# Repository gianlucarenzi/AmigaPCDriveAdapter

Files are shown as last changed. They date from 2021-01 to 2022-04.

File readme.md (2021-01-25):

# Amiga Floppy to PC Floppy Adapter

Created by Gianluca Renzi (C) 2018
 E-Mail:
- <icjtqr@gmail.com>
- <gianlucarenzi@eurek.it>

# PCB Revision History

- V0.1 Initial Revision 2018 Made with Kicad 4.x
- V1.0 First (BAD) PCB revision from transition from Kicad 4.x to Kicad 5.x
- V2.0 PCB Revision entirely made on Kicad 5. No library from Kicad 4 anymore.

# What is it?
It is a simple but powerful adapter to use internally in any Amiga Computer!
It must be connected to the floppy disk drive 34-pin interface on the drive
itself, then hooked up with the original cables from Amiga motherboard.

# Images
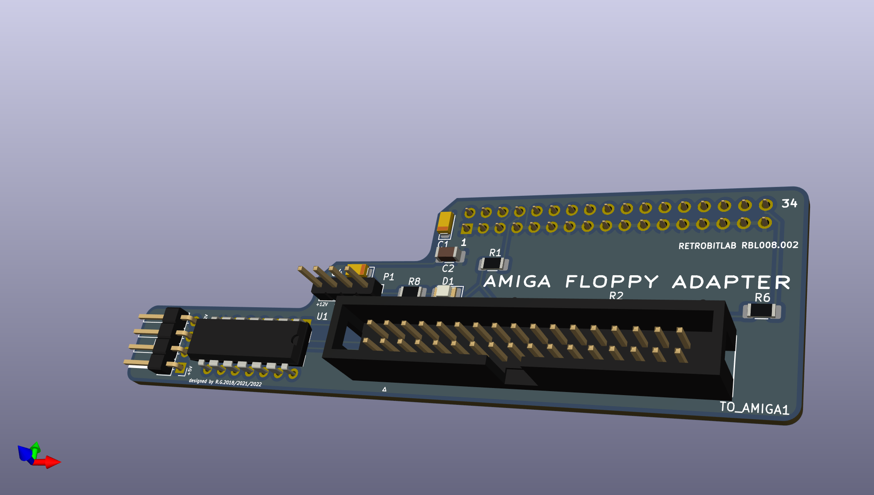
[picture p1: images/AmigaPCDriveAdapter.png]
Board Overall

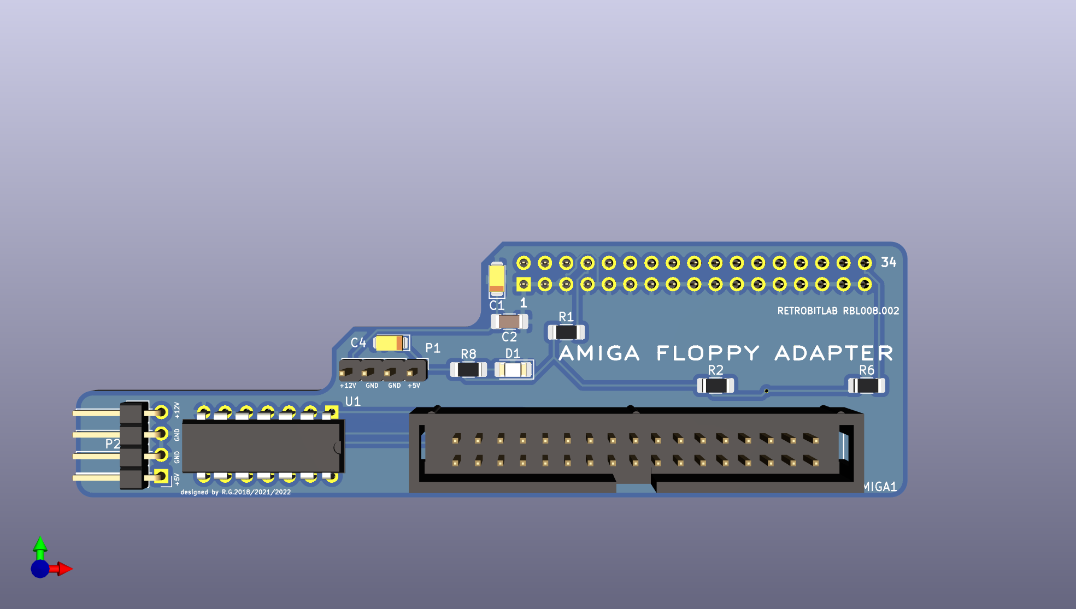
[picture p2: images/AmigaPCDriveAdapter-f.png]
Board Front

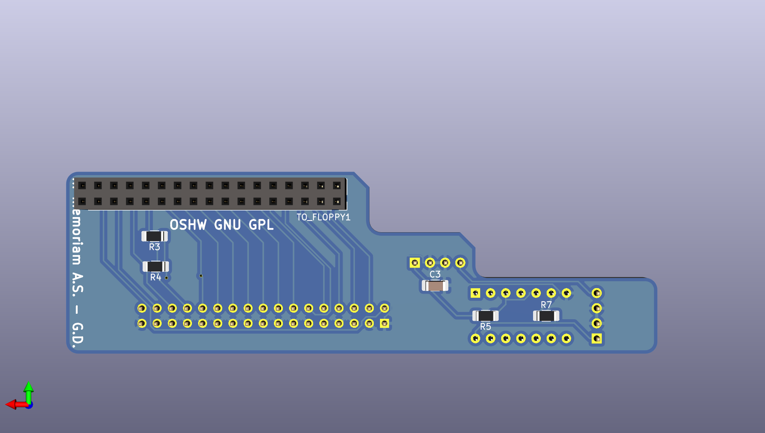
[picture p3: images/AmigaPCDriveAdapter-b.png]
Board Back


# What's changed?

- V0.1 Initial release (2018)
- V1.0 From Kicad 4 to Kicad 5 (2019). I found a bug in PCB version automatically generated by Kicad 5 from Kicad 4: All the hand soldering pads are way too large and they are overlapping each other short-circuiting every signal with a large series of resistors. Thanks to: __Stefan Gammelgaard(BM)__ to point me out on this issue.
- V2.0 Updated and Corrected for usage in Kicad 5 (2020)

# Bill of materials (from Digikey)

| Quantity | Digikey's Part No. | Manufacturer's Part. No. | Description | PCB/Schematic's Reference |
| --- | ---| --- | --- | --- |
| 2 | 445-10000-1-ND	 | CGA5H2X8R2A104K115AD	 | CAP CER 0.1UF 100V 1206 EPOXY | C2, C3 |
| 10	 | P2.2KECT-ND	 | ERJ-8GEYJ222V	 | RES SMD 2.2K OHM 5% 1/4W 1206 | R1, R2, R3, R4, R5, R6, R7  |
| 1	 | 754-APTR3216SECK/J3-PRVCT-ND | APTR3216SECK/J3-PRV	 | LED SMD	 | D1 |
| 1 | WM4002-ND |	0022032041	 | CONN HEADER VERT 4POS 2.54MM	 | P1 |
| 1 | 609-3407-ND | 68016-404HLF | CONN HEADER R/A 4POS 2.54MM | P2 |
| 1 | 541-CRCW1206330RJNEACCT-ND | CRCW1206330RJNEAC | RES 330 OHM 5% 1/4W 1206 | R8 |
| 1 | S9174-ND | SBH11-PBPC-D17-ST-BK | CONN HEADER VERT 34POS 2.54MM | TO_AMIGA1 |
| 1 | ED3068-ND | SH2-34G-PT | CONN RCPT 34POS 0.1 GOLD PCB  | TO_FLOPPY1 |
| 1 | 296-1664-5-ND | SN74LS38N | IC GATE NAND 4CH 2-INP 14DIP  | U1 |
| 2 | 478-10757-1-ND | TPSA106K016R1000 | CAP TANT 10UF 10% 16V 1206 | C1, C4 |

# Licence
This entire project is available under the GNU General Public License v3 licence.
See licence.txt for more details.

Additional Copyright/License
Permission is hereby granted, free of charge, to any person obtaining a copy of this software and associated documentation files (the "Software"), to deal in the Software without restriction, including without limitation the rights to use, copy, modify, merge, publish, distribute, sublicense, and/or sell copies of the Software, and to permit persons to whom the Software is furnished to do so, subject to the following conditions:

The above copyright notice and this permission notice shall be included in all copies or substantial portions of the Software/Hardware.

THE SOFTWARE/HARDWARE IS PROVIDED "AS IS", WITHOUT WARRANTY OF ANY KIND, EXPRESS OR IMPLIED, INCLUDING BUT NOT LIMITED TO THE WARRANTIES OF MERCHANTABILITY, FITNESS FOR A PARTICULAR PURPOSE AND NONINFRINGEMENT. IN NO EVENT SHALL THE AUTHORS OR COPYRIGHT HOLDERS BE LIABLE FOR ANY CLAIM, DAMAGES OR OTHER LIABILITY, WHETHER IN AN ACTION OF CONTRACT, TORT OR OTHERWISE, ARISING FROM, OUT OF OR IN CONNECTION WITH THE SOFTWARE/HARDWARE OR THE USE OR OTHER DEALINGS IN THE SOFTWARE/HARDWARE.

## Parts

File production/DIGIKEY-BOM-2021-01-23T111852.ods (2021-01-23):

Indice | Quantità | Codice componente | Codice produttore | Descrizione | Riferimento cliente | Disponibile | Ordine arretrato | Prezzo unitario | Prezzo totale EUR
1 | 2 | 445-10000-1-ND | CGA5H2X8R2A104K115AD | CAP CER 0.1UF 100V 1206 EPOXY | C2, C3 | 2 | 0 | 63.000 | 126
2 | 10 | P2.2KECT-ND | ERJ-8GEYJ222V | RES SMD 2.2K OHM 5% 1/4W 1206 | R1,..R7 | 10 | 0 | 4.800 | 48
3 | 1 | 754-APTR3216SECK/J3-PRVCT-ND | APTR3216SECK/J3-PRV | LED SMD | D1 | 1 | 0 | 55.000 | 55
4 | 1 | WM4002-ND | 0022032041 | CONN HEADER VERT 4POS 2.54MM | P1 | 1 | 0 | 27.000 | 27
5 | 1 | 609-3407-ND | 68016-404HLF | CONN HEADER R/A 4POS 2.54MM | P2 | 1 | 0 | 15.000 | 15
6 | 1 | 541-CRCW1206330RJNEACCT-ND | CRCW1206330RJNEAC | RES 330 OHM 5% 1/4W 1206 | R8 | 1 | 0 | 8.000 | 8
7 | 1 | S9174-ND | SBH11-PBPC-D17-ST-BK | CONN HEADER VERT 34POS 2.54MM | TO_AMIGA1 | 1 | 0 | 55.000 | 55
8 | 1 | ED3068-ND | SH2-34G-PT | CONN RCPT 34POS 0.1 GOLD PCB | TO_FLOPPY1 | 1 | 0 | 129.000 | 129
9 | 1 | 296-1664-5-ND | SN74LS38N | IC GATE NAND 4CH 2-INP 14DIP | U1 | 1 | 0 | 77.000 | 77
10 | 2 | 478-10757-1-ND | TPSA106K016R1000 | CAP TANT 10UF 10% 16V 1206 | C1, C4 | 2 | 0 | 49.000 | 98

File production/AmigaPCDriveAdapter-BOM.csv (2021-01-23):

Id | Designator | Package | Quantity | Designation | Supplier and ref
1 | U1 | DIP-14_W7.62mm | 1 | 74LS38
2 | C1,C4 | CP_EIA-3216-12_Kemet-S | 2 | 10uF
3 | C2,C3 | C_1206_3216Metric_Pad1.42x1.75mm_HandSolder | 2 | 100nF
4 | D1 | LED_1206_3216Metric_Pad1.42x1.75mm_HandSolder | 1 | Led_Small
5 | P1 | PinHeader_1x04_P2.54mm_Vertical | 1 | CONN_01X04
6 | P2 | PinHeader_1x04_P2.54mm_Horizontal | 1 | CONN_01X04
7 | R1,R2,R3,R4,R5,R7 | R_1206_3216Metric_Pad1.42x1.75mm_HandSolder | 6 | 2.2K
8 | R6 | R_1206_3216Metric_Pad1.42x1.75mm_HandSolder | 1 | 2,2K
9 | R8 | R_1206_3216Metric_Pad1.42x1.75mm_HandSolder | 1 | 330
10 | TO_AMIGA1 | IDC-Header_2x17_P2.54mm_Vertical_Lock | 1 | CONN_02X17
11 | TO_FLOPPY1 | PinSocket_2x17_P2.54mm_Vertical | 1 | CONN_02X17
12 | OSHW | OSHW-Logo_5.7x6mm_SilkScreen | 1 | OSHW-Logo_5.7x6mm_SilkScreen

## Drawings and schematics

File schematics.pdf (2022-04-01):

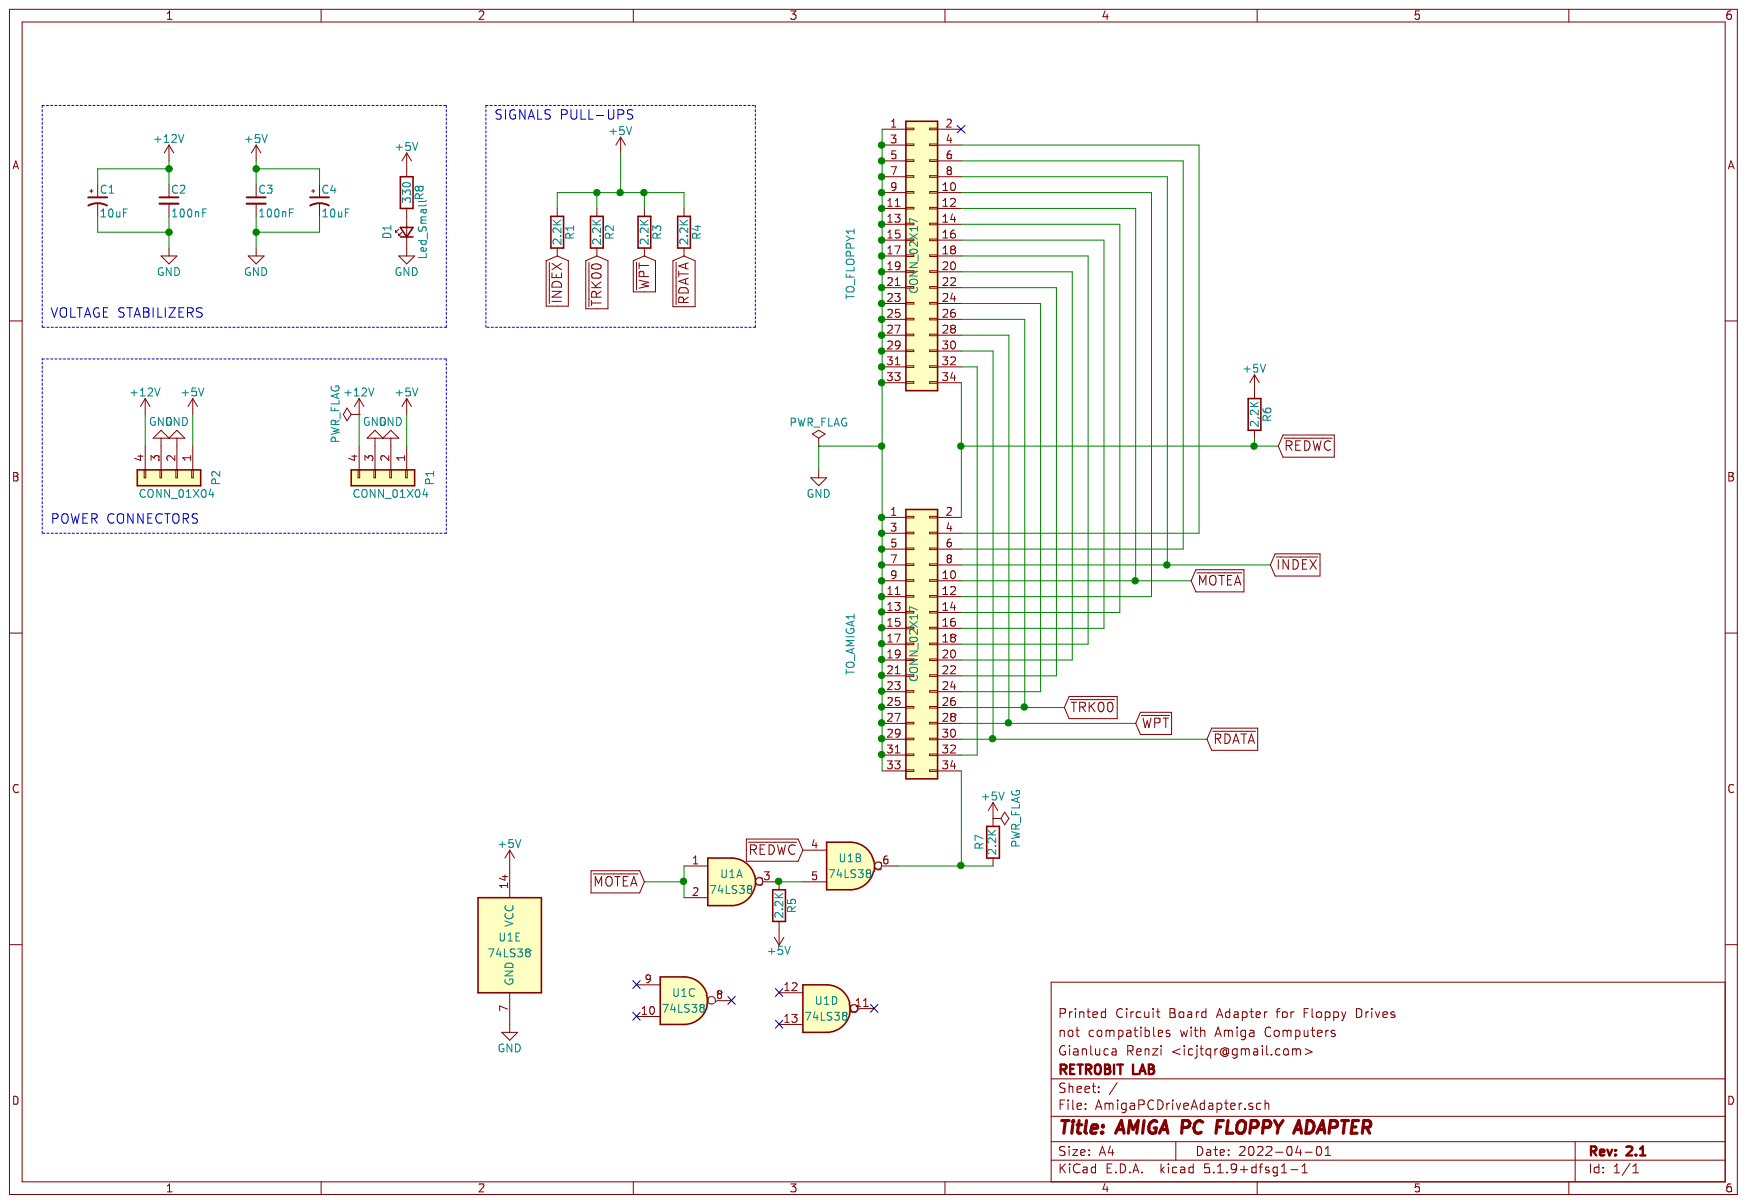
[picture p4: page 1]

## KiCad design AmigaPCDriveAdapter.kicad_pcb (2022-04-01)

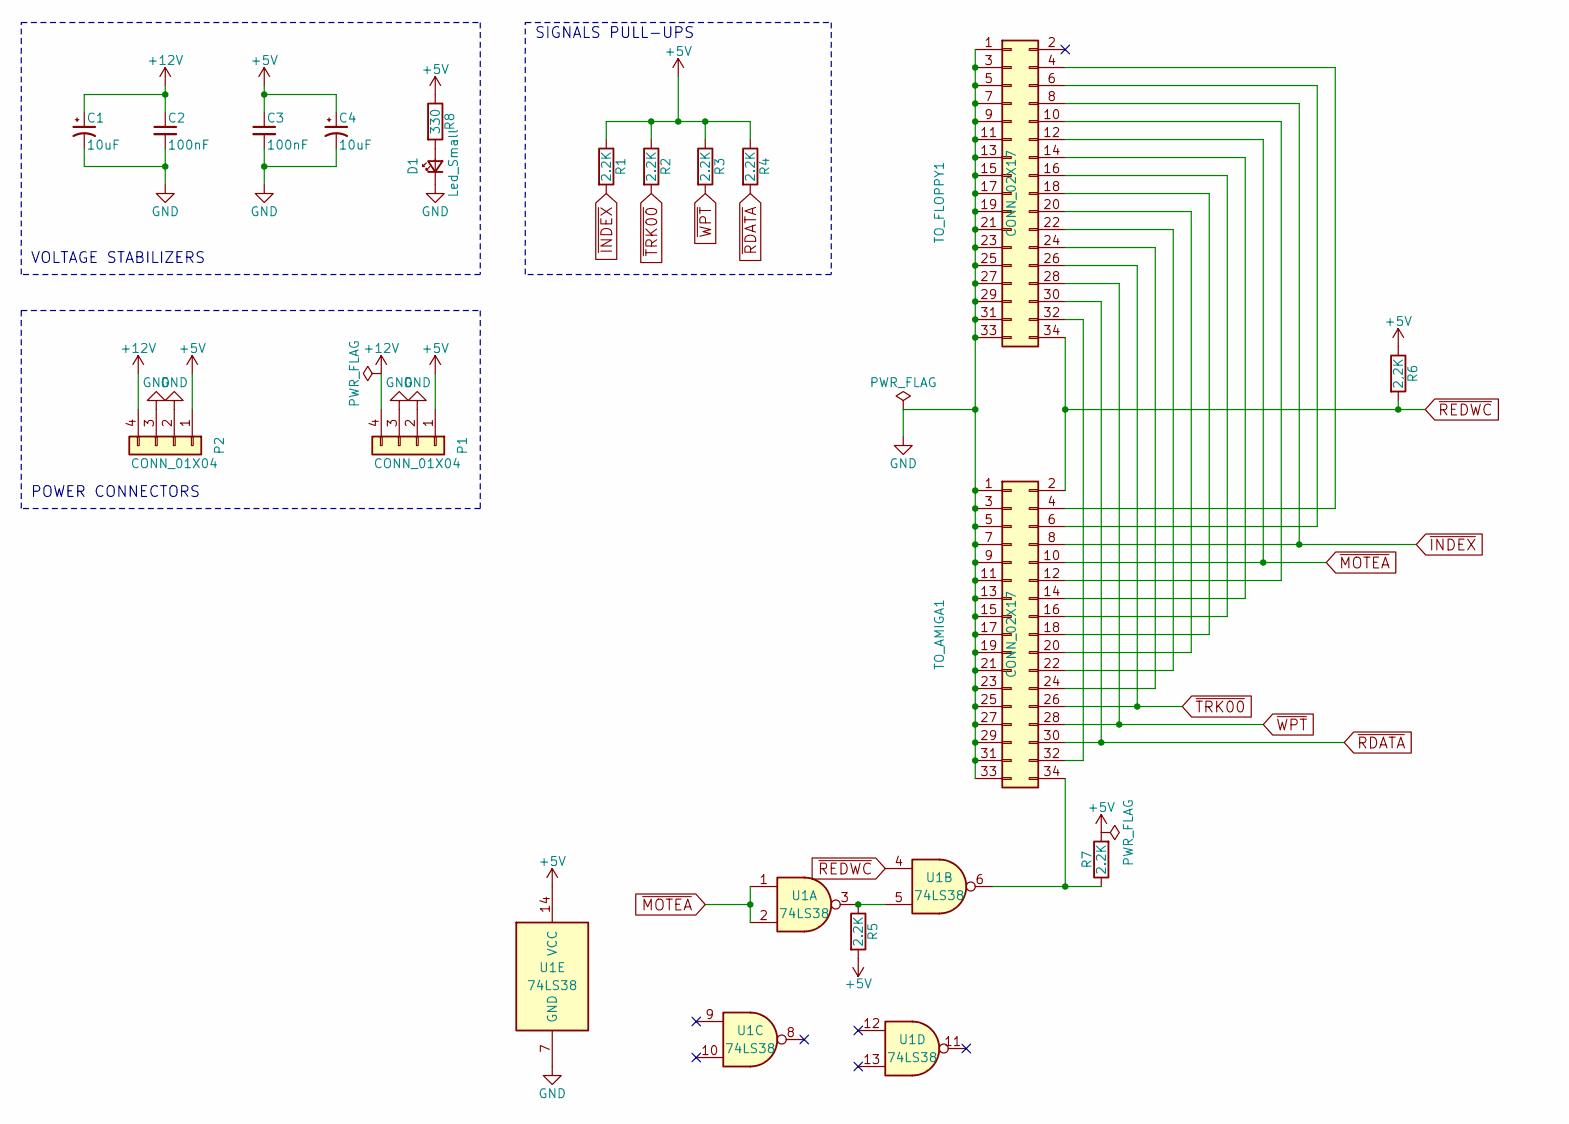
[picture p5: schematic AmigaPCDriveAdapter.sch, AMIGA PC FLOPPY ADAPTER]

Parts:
C1, C4: 10uF; CP_EIA-3216-12_Kemet-S
C2, C3: 100nF; C_1206_3216Metric_Pad1.33x1.80mm_HandSolder
D1: Led_Small; LED_1206_3216Metric_Pad1.42x1.75mm_HandSolder
P1: CONN_01X04; PinHeader_1x04_P2.54mm_Vertical
P2: CONN_01X04; PinHeader_1x04_P2.54mm_Horizontal
R1, R2, R3, R4, R5, R7: 2.2K; R_1206_3216Metric_Pad1.30x1.75mm_HandSolder
R6: 2,2K; R_1206_3216Metric_Pad1.30x1.75mm_HandSolder
R8: 330; R_1206_3216Metric_Pad1.30x1.75mm_HandSolder
TO_AMIGA1: CONN_02X17; IDC-Header_2x17_P2.54mm_Vertical_Lock
TO_FLOPPY1: CONN_02X17; PinSocket_2x17_P2.54mm_Vertical
U1: 74LS38; DIP-14_W7.62mm

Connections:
+5V: C3.1, C4.1, P1.1, P2.1, R1.1, R2.1, R3.1, R4.1, R5.2, R6.1, R7.2, R8.1, U1.14 (VCC)
+12V: C1.1, C2.1, P1.4, P2.4
GND: C1.2, C2.2, C3.2, C4.2, D1.1 (K), P1.2, P1.3, P2.2, P2.3, TO_AMIGA1.1, TO_AMIGA1.3, TO_AMIGA1.5, TO_AMIGA1.7, TO_AMIGA1.9, TO_AMIGA1.11, TO_AMIGA1.13, TO_AMIGA1.15, TO_AMIGA1.17, TO_AMIGA1.19, TO_AMIGA1.21, TO_AMIGA1.23, TO_AMIGA1.25, TO_AMIGA1.27, TO_AMIGA1.29, TO_AMIGA1.31, TO_AMIGA1.33, TO_FLOPPY1.1, TO_FLOPPY1.3, TO_FLOPPY1.5, TO_FLOPPY1.7, TO_FLOPPY1.9, TO_FLOPPY1.11, TO_FLOPPY1.13, TO_FLOPPY1.15, TO_FLOPPY1.17, TO_FLOPPY1.19, TO_FLOPPY1.21, TO_FLOPPY1.23, TO_FLOPPY1.25, TO_FLOPPY1.27, TO_FLOPPY1.29, TO_FLOPPY1.31, TO_FLOPPY1.33, U1.7 (GND)
unnamed: D1.2 (A), R8.2
unnamed: R5.1, U1.3, U1.5
unnamed: R7.1, TO_AMIGA1.34, U1.6
unnamed: TO_AMIGA1.4, TO_FLOPPY1.4
unnamed: TO_AMIGA1.6, TO_FLOPPY1.6
unnamed: TO_AMIGA1.12, TO_FLOPPY1.10
unnamed: TO_AMIGA1.14, TO_FLOPPY1.14
unnamed: TO_AMIGA1.16, TO_FLOPPY1.16
unnamed: TO_AMIGA1.18, TO_FLOPPY1.18
unnamed: TO_AMIGA1.20, TO_FLOPPY1.20
unnamed: TO_AMIGA1.22, TO_FLOPPY1.22
unnamed: TO_AMIGA1.24, TO_FLOPPY1.24
unnamed: TO_AMIGA1.32, TO_FLOPPY1.32
~INDEX: R1.2, TO_AMIGA1.8, TO_FLOPPY1.8
~MOTEA: TO_AMIGA1.10, TO_FLOPPY1.12, U1.1, U1.2
~RDATA: R4.2, TO_AMIGA1.30, TO_FLOPPY1.30
~REDWC: R6.2, TO_AMIGA1.2, TO_FLOPPY1.34, U1.4
~TRK00: R2.2, TO_AMIGA1.26, TO_FLOPPY1.26
~WPT: R3.2, TO_AMIGA1.28, TO_FLOPPY1.28

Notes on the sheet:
POWER CONNECTORS
VOLTAGE STABILIZERS
SIGNALS PULL-UPS

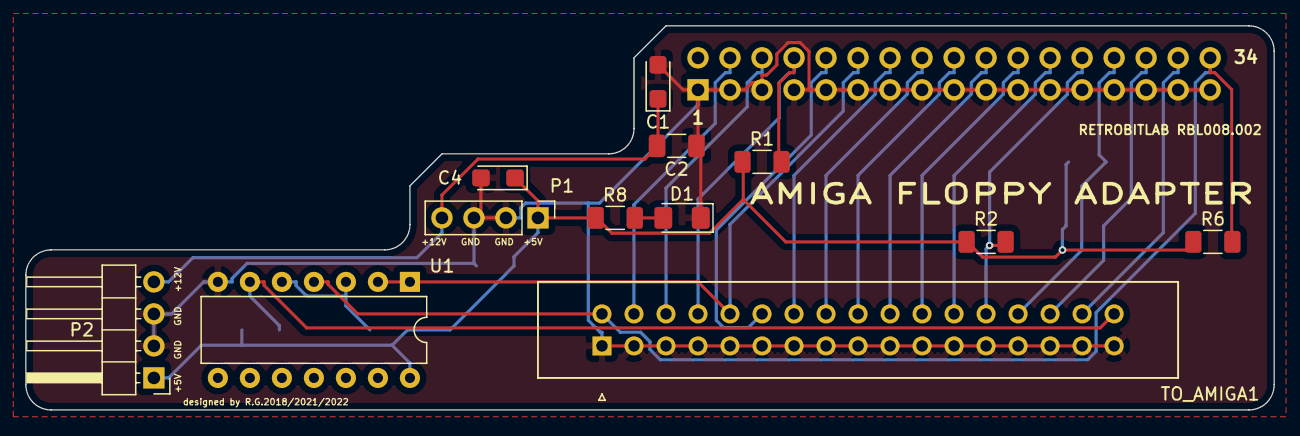
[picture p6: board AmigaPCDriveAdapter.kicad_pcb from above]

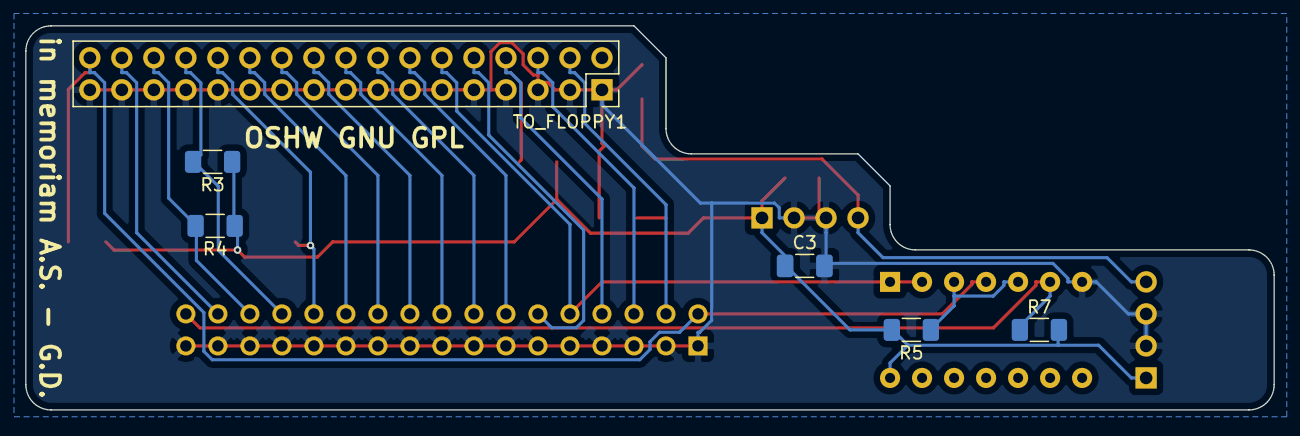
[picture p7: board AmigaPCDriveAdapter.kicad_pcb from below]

Board: 2 copper layers, 99.1 x 30.5 mm, 18 parts (6 on the bottom side), 22 nets.

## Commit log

2018-12-23 First Import in Git
    [AmigaPCDriveAdapter-B.Cu.gbl, AmigaPCDriveAdapter-B.Mask.gbs, AmigaPCDriveAdapter-B.Paste.gbp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]
2019-01-20 Update libraries
    [AmigaPCDriveAdapter.sch]
2019-03-01 Correct some libraries issues. Part TWO
    [AmigaPCDriveAdapter-B.Cu.gbl, AmigaPCDriveAdapter-B.Mask.gbs, AmigaPCDriveAdapter-B.Paste.gbp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]
2019-03-01 Added board overall
2019-06-17 Modified in VM x86
    [AmigaPCDriveAdapter-B.Cu.gbl, AmigaPCDriveAdapter-B.Mask.gbs, AmigaPCDriveAdapter-B.Paste.gbp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]
2019-06-17 Added BOM (generated from PCB)
    [AmigaPCDriveAdapter-BOM.csv]
2021-01-23 Added after update the schematics for Kicad 5 from Kicad 4
2021-01-23 Version Kicad 5 V2.0
2021-01-23 Added from Kicad 5
    [AmigaPCDriveAdapter-NPTH.drl, AmigaPCDriveAdapter-PTH.drl]
2021-01-23 Updated to drop the rescue file
    [AmigaPCDriveAdapter.kicad_pcb, AmigaPCDriveAdapter.sch]
2021-01-23 Update from PCB_NEW Kicad 5
    [AmigaPCDriveAdapter-BOM.csv]
2021-01-23 Gerber Files for Production v2.0
2021-01-23 Modified TANTALUM Cap for a more common type.
    [DIGIKEY-BOM-2021-01-23T111852.ods]
2022-04-01 Generated with latest version of KiCAD 5.1.9
    [AmigaPCDriveAdapter-B_Cu.gbl, AmigaPCDriveAdapter-B_Mask.gbs, AmigaPCDriveAdapter-B_Paste.gbp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]

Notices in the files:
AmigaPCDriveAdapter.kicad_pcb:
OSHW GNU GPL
